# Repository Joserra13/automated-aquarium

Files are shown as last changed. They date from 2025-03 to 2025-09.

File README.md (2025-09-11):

# Automated Aquarium

## Overview

The Automated Aquarium project is designed to transform a traditional aquarium into a smart IoT device. By integrating various sensors and a camera, users can remotely monitor and control multiple aspects of their aquarium environment. Key features include live streaming of the aquarium on Twitch, real-time sensor data visualization, and comprehensive environmental management. The project utilizes a range of technologies, from web development to embedded software.

> **Note:** This is an ongoing project. Features and implementations may evolve over time.

Comprehensive documentation and setup guides are available to assist you in configuring and maintaining your automated aquarium.

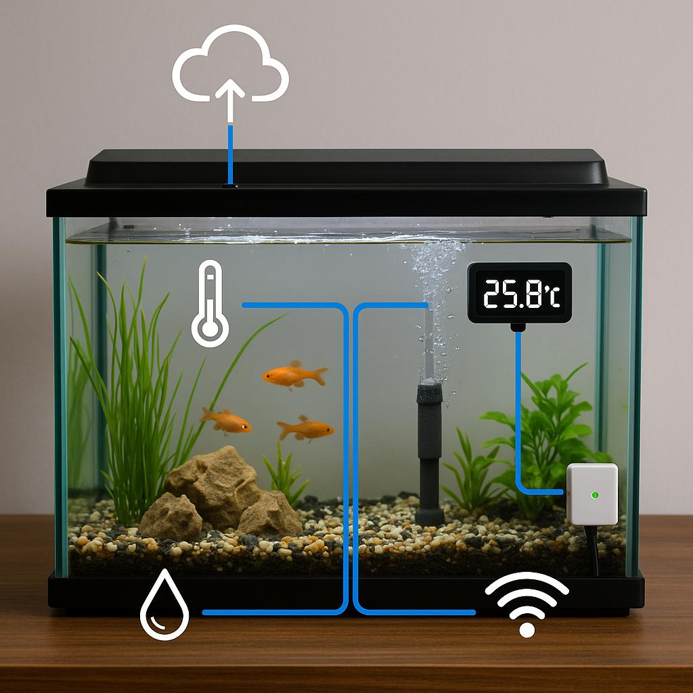
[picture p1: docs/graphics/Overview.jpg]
Architecture


## Automated Aquarium Website

A dedicated website, built with Next.js, serves as the user interface for monitoring and controlling your automated aquarium.

<p align="center">
  <a href="https://automated-aquarium.com">
    
  </a>
</p>

For more information and to get started with the web interface, visit the [automated-aquarium-web](https://github.com/Joserra13/automated-aquarium-web) repository.

<p align="center">
  <a href="https://github.com/Joserra13/automated-aquarium-web">
    
  </a>
</p>

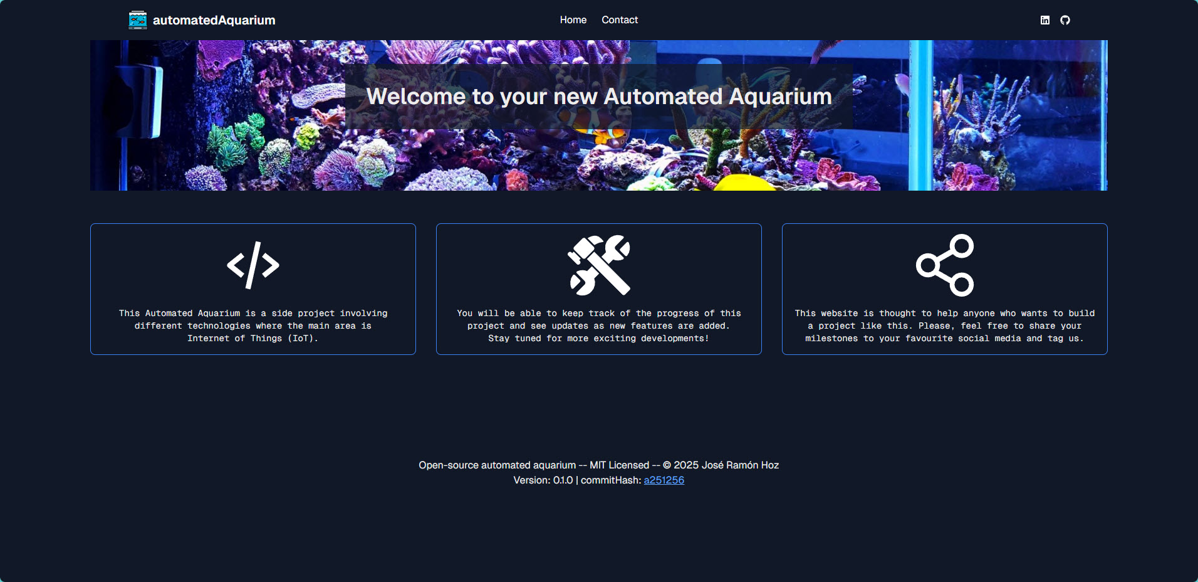
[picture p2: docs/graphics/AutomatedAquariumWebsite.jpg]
AutomatedAquariumWebsite (https://automated-aquarium.com)


## Automated Aquarium Backend

The server, built with node.js, which handles different services where I store data from the aquarium. 

For more information and to get started with the backend of this project, visit the [automated-aquarium-backend](https://github.com/Joserra13/automated-aquarium-backend) repository.

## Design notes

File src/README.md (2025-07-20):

# Components

## Structure

This directory contains detailed information about the components that power the Automated Aquarium system. Additional items will be included as they are developed.

## List of Components

- [Automatic Feeder](./RaspberryPi-Pico-W/Feeder/)
- [Underwater thermistor](./RaspberryPi-Pico-W/Underwater%20Thermistor/)
- [Water Level Sensor](./RaspberryPi-Pico-W/Water%20Level%20Detector/)

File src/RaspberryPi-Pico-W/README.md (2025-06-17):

# Raspberry Pi Pico W

> [!WARNING]  
> To obtain the Firebase keys required for your `credentials.py` file, refer to the [Firebase setup guide](../../../docs/firebase.md). In addition to the Firebase keys, you must also provide your WiFi SSID and password in this file.

## Schematic

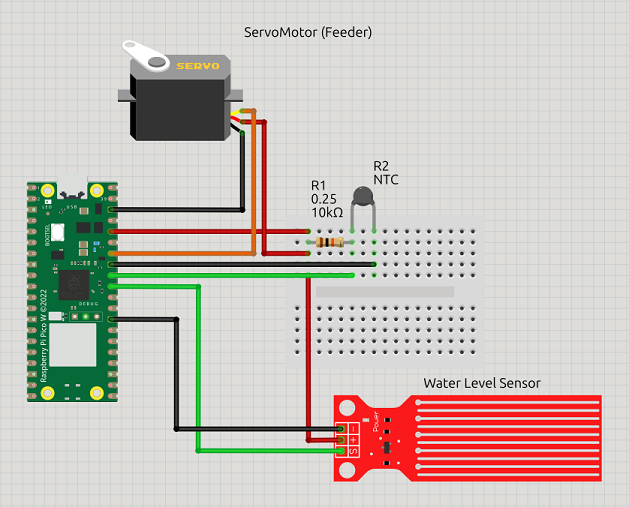
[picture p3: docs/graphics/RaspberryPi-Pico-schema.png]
RaspberryPi-Pico-W-Schematic


## Code

First, connect the Raspberry Pi Pico W to your IDE by following the [official setup guide](https://projects.raspberrypi.org/en/projects/getting-started-with-the-pico/3).

To run the code, you will need the **Servo** object from the **micropython-servo** library:

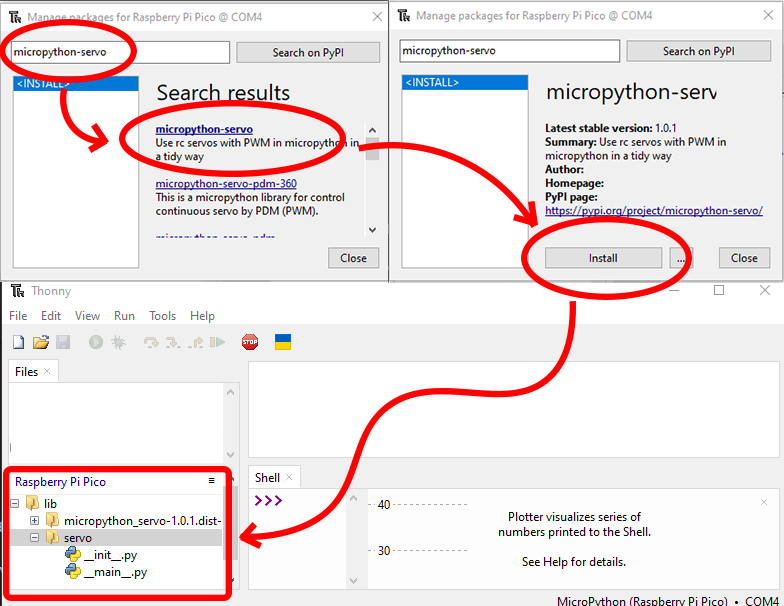
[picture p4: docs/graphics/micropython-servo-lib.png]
Add package


Once the package is installed, copy the [main.py](./main.py), [credentials.py.example](./credentials.py.example) (rename to `credentials.py`), and [utils.py](./utils.py) files to your Raspberry Pi Pico, and run `main.py` in Thonny IDE.

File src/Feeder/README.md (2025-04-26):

# Fish Feeder

## Overview

The automatic fish feeder allows to schedule diferent timeslots to feed your fishes automatically. You only need to worry about placing the food in the storage so, the feeder will provide the food periodically to your fishes.

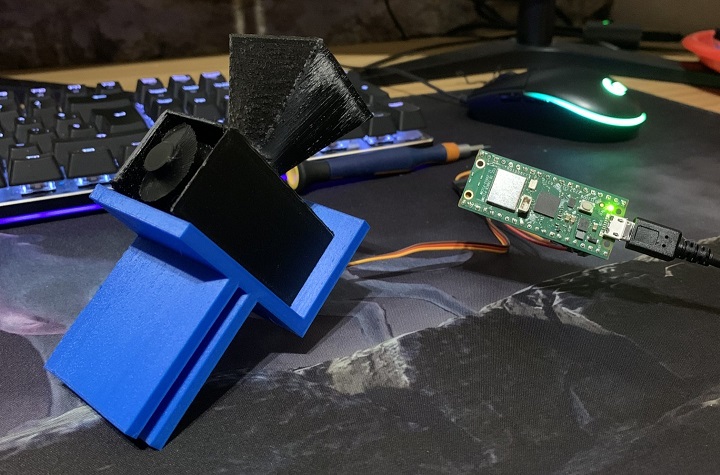
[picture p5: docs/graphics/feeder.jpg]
Feeder


## Materials needed

### Hardware

- Raspberry Pi Pico W (+ charging cable).
- 3d parts printed.
- SG90 Servo (Continuous Rotation).

    >Most of the SG90 servos can only rotate 180 degrees. If this is your case, you can follow the [explained steps](../../docs/hack-servo.md) to hack your servo and convert it into a 360 rotation.

- 3x Male to Female wires.

### Software

- Thonny IDE. See [documentation](https://thonny.org/).

## Circuit

Depending on the device you are using, this schematic might change. In my case, I am using a Raspberry Pi pico W, you can check out the pinout in the following [Raspberry Pi pico documentation](https://www.raspberrypi.com/documentation/microcontrollers/pico-series.html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).

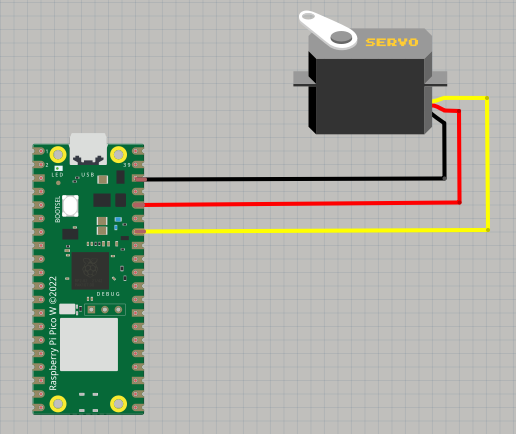
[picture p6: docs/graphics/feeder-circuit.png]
Feeder-circuit


## 3D pieces and assembling

Since some pieces are needed to build the feeder, you can print the different parts from the files under the [3D models](./3D%20models) folder. For the main body, I had to remove the original piece where the Wemos board is stored. In addition, I printed a Raspberry Pi pico W case which I glued to the main body.

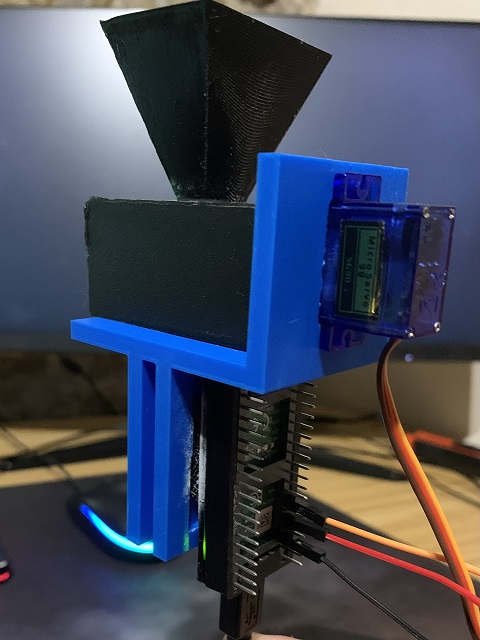
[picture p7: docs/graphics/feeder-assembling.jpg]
Feeder assembling


> [!NOTE]  
> The original 3D files come from the post in [Instructables](https://www.instructables.com/Aquassist-DIY-Automatic-Fish-Feeder-With-Companion/) from [CodersCafeTech](https://www.instructables.com/member/CodersCafeTech/)

## Code

First of all you need to connect the Raspberry Pi pico to your IDE. You can do so by following the original [documentation](https://projects.raspberrypi.org/en/projects/getting-started-with-the-pico/3) from Raspberry Pi.

To run the code, you will need the **Servo** object from the **micropython-servo** library:

Add package

Once, the package is installed, copy the [code](./main.py) and run the script in the Thonny IDE.

## References

- Original idea from CodersCafeTech in [Instructables](https://www.instructables.com/Aquassist-DIY-Automatic-Fish-Feeder-With-Companion/).
- Raspberry Pi pico cover model from [Thingiverse](https://www.thingiverse.com/thing:4793356).

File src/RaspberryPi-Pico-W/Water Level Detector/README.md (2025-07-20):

# Water Level Detector

## Overview

Monitoring water level is essential for maintaining a stable aquatic environment. By adding a water level detector to the project, you can accurately measure and track water levels in real time. This enables automated responses, such as refilling the tank or sending alerts, ensuring optimal conditions for aquatic life and preventing issues caused by low water levels.

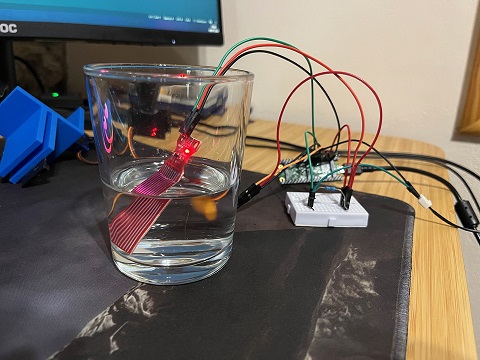
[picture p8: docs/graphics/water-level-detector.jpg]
Water level detector


## Materials Needed

### Hardware

- Raspberry Pi Pico W (with charging cable)
- Water level sensor (analog or digital)
- 3x Female-to-Female jumper wires

### Software

- Thonny IDE. See the [official documentation](https://thonny.org/).

## Circuit

The schematic may vary depending on your device. For the Raspberry Pi Pico W, refer to the [official pinout documentation](https://www.raspberrypi.com/documentation/microcontrollers/pico-series.html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).

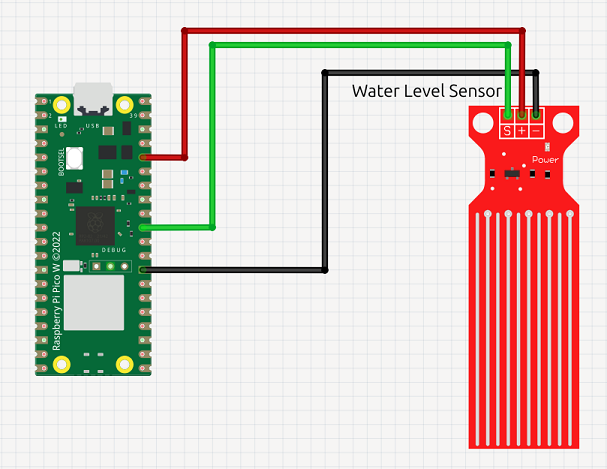
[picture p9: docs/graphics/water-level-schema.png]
Water level circuit


## Code

The code for this project is available under the [RaspberryPi-Pico-W](../) directory.

## References

- [Analog Inputs in Raspberry Pi Pico](https://controlautomaticoeducacion.com/sistemas-embebidos/micropython/adc-pico-esp/)

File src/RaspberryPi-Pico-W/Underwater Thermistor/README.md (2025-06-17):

# Water Thermistor

## Overview

Monitoring water temperature is crucial for maintaining a healthy aquatic environment. By adding a water thermistor to the project, you can accurately measure and track temperature changes in real time. This enables automated responses, such as activating heaters or sending alerts, ensuring optimal conditions for aquatic life and preventing potential issues caused by temperature fluctuations.

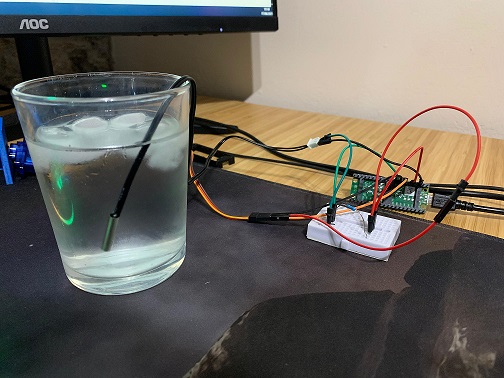
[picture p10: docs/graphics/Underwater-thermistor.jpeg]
Underwater thermistor


## Materials Needed

### Hardware

- Raspberry Pi Pico W (with charging cable)
- NTC thermistor 10K + 0.5%
- 10K Resistor
- Minibreadboard
- 2x Male-to-Male jumper wires
- 3x Male-to-Female jumper wires

### Software

- Thonny IDE. See the [official documentation](https://thonny.org/).

## Circuit

The schematic may vary depending on your device. For the Raspberry Pi Pico W, refer to the [official pinout documentation](https://www.raspberrypi.com/documentation/microcontrollers/pico-series.html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).

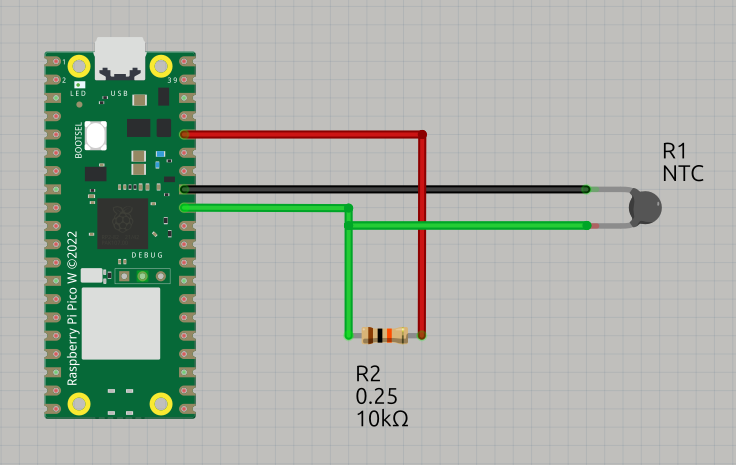
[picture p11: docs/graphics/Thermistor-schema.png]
Thermostat circuit


## Code

The code for this project is available under the [RaspberryPi-Pico-W](../) directory.

## References  

- [Project 29：Temperature Instrument](https://docs.keyestudio.com/projects/KS3025/en/latest/Python_Raspberry-Pi/2.Projects/Project%2029%EF%BC%9ATemperature%20Instrument.html) from Raspberry Pi Pico Learnin Kit.

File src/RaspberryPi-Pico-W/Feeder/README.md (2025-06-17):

# Fish Feeder

## Overview

The automatic fish feeder enables you to schedule multiple feeding times for your fish. Simply ensure that food is placed in the storage compartment—the feeder will automatically dispense food at the designated intervals.

Feeder

## Materials Needed

### Hardware

- Raspberry Pi Pico W (with charging cable)
- 3D-printed parts
- SG90 Servo (Continuous Rotation)

    > **Note:** Most SG90 servos are limited to 180-degree rotation. If this applies to your servo, you can follow the [instructions](../../../docs/hack-servo.md) to modify it for 360-degree rotation.

- 3x Male-to-Female jumper wires

### Software

- Thonny IDE. See the [official documentation](https://thonny.org/).

## Circuit

The schematic may vary depending on your device. For the Raspberry Pi Pico W, refer to the [official pinout documentation](https://www.raspberrypi.com/documentation/microcontrollers/pico-series.html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).

Feeder-circuit

## 3D Parts and Assembly

Several 3D-printed components are required to build the feeder. You can print these parts from the files in the [3D models](./3D%20models) folder. For the main body, the original piece designed for the Wemos board was removed. Additionally, a Raspberry Pi Pico W case was printed and attached to the main body.

Feeder assembling

> [!NOTE]  
> The original 3D files are from [CodersCafeTech](https://www.instructables.com/member/CodersCafeTech/) on [Instructables](https://www.instructables.com/Aquassist-DIY-Automatic-Fish-Feeder-With-Companion/).

## Code

The code for this project is available under the [RaspberryPi-Pico-W](../) directory.

## References

- Original concept by CodersCafeTech on [Instructables](https://www.instructables.com/Aquassist-DIY-Automatic-Fish-Feeder-With-Companion/).
- Raspberry Pi Pico cover model from [Thingiverse](https://www.thingiverse.com/thing:4793356).

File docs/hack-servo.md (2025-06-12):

# Convert SG90 servo into a continuous movement one

## Index

- [Overview](#overview)
- [How can I hack it?](#how-can-i-hack-it)
- [How does it work?](#how-does-it-work)
- [References](#references)

## Overview

Some SG90 servos can only rotate 180 degrees. Since this was the case of the one I own, I needed to perform some modifications into the hardware to convert it into a continuous movement servo.

> [!WARNING]  
> This guide is provided for informational purposes only. Modifying a servo involves risks, including potential damage to your equipment or injury. Proceed at your own risk. I take no responsibility for any harm, damage, or loss resulting from the use or misuse of this information.

## How can I hack it?

1. Disassemble servo.

2. Remove the ending part of the gear shown below:

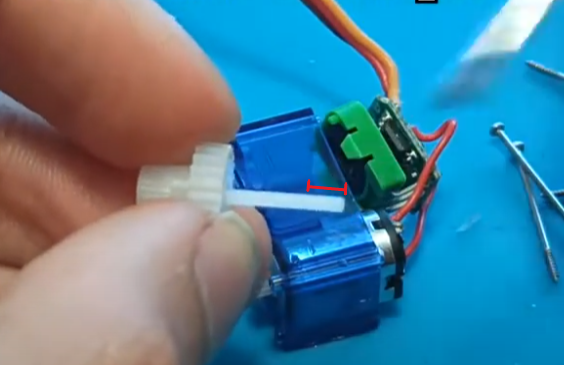
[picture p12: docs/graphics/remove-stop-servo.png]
hack-servo
    

3. Load the following script into your device (e.g. an Raspberry Pi pico) to calibrate the potentiometer.
The potentiometer should me modified so when **my_servo.write(90)** is executed, the servo is fully stopped.

    >**Note**: This script works for python/micropython boards. For Arduinos, you should use another script but following the same commands for the movements.

    ```py
    import time
    from servo import Servo

    # Create our Servo object, assigning the
    # GPIO pin connected the PWM wire of the servo
    my_servo = Servo(pin_id=28)

    while True:
        my_servo.write(90)  # Set the Servo to stop
        time.sleep_ms(1000)  # Wait for 1 second
        
        my_servo.write(0)  # Move the servo clockwise
        time.sleep_ms(1000)  
        
        my_servo.write(180)  # Move the servo counterclockwise
        time.sleep_ms(1000)  
    ```

4. Glue the potentiometer to secure a fixed position and prevent modifications due to vibrations:
    
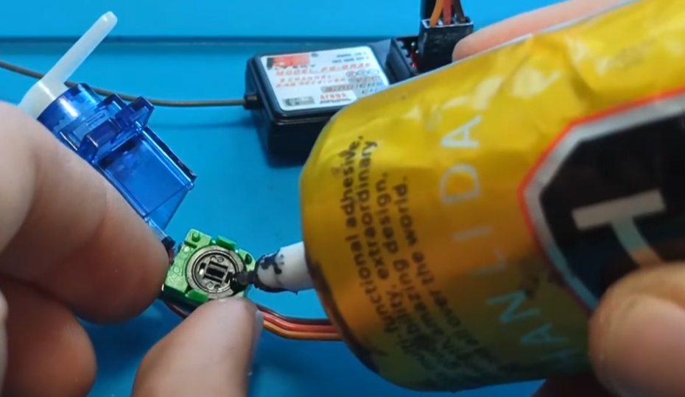
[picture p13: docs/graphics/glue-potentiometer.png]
Glue potentiometer
    

5. Test movement again to check if the servo works as intended.

6. Assemble potentiometer again.

## How does it work?

Continuous rotation servos work similarly to regular angular servos. If your library uses input angles of 0–180°, you can set the speed and direction of a continuous servo like this:
  - 180 - 100% speed counterclockwise
  - 135 - 50% speed counterclockwise
  - 90 - Stopped
  - 45 - 50% speed clockwise
  - 0 - 100% speed clockwise

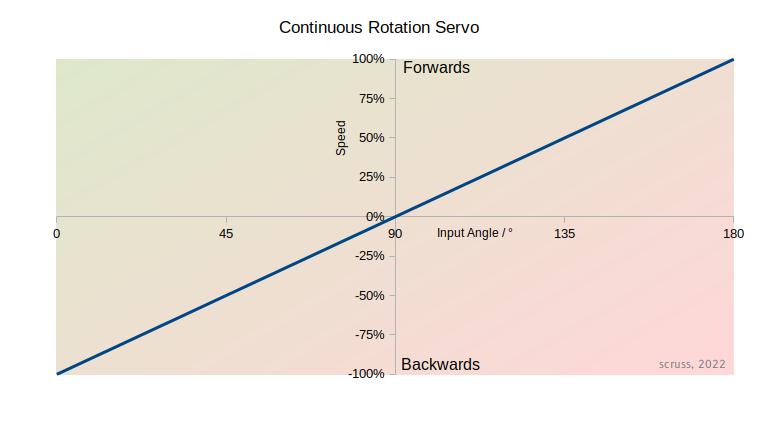
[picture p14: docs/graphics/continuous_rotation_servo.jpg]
Continuous servo graphic


## References:

- [Hack the SG90 servo to make it continuous rotation](https://www.youtube.com/watch?v=4Z-j6bUJTQ8) from H.R.E Systems in Youtube.

- [Calibration script](https://core-electronics.com.au/guides/getting-started-with-servos-examples-with-raspberry-pi-pico/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,Remix%202%20%2D%20Rotational%20Servo%20Control,-Finally%2C%20let%27s%20have) for the potentiometer.

- [Continuous rotation servo graphic](https://forums.raspberrypi.com/viewtopic.php?t=341927) from the Raspberry Pi Forum.

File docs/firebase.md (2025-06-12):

# Setting Up the Firebase Project

## Table of Contents

- [Obtain Credentials](#obtain-credentials)
- [Create the Database](#create-the-database)
- [Accessing the Database](#accessing-the-database)

## Obtain Credentials

1. Navigate to the [Firebase Console](https://console.firebase.google.com/u/3/) and create a new project, following the default configuration steps.

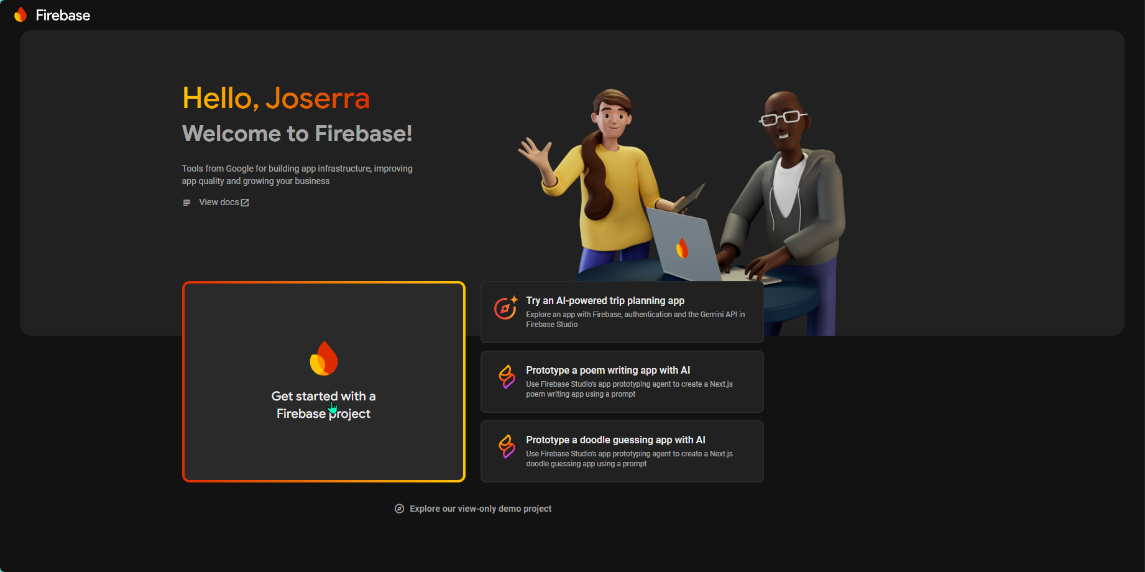
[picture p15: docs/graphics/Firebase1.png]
Get started with Firebase
   

2. Go to the **Authentication** tab and enable both the Email/Password and Google sign-in methods:

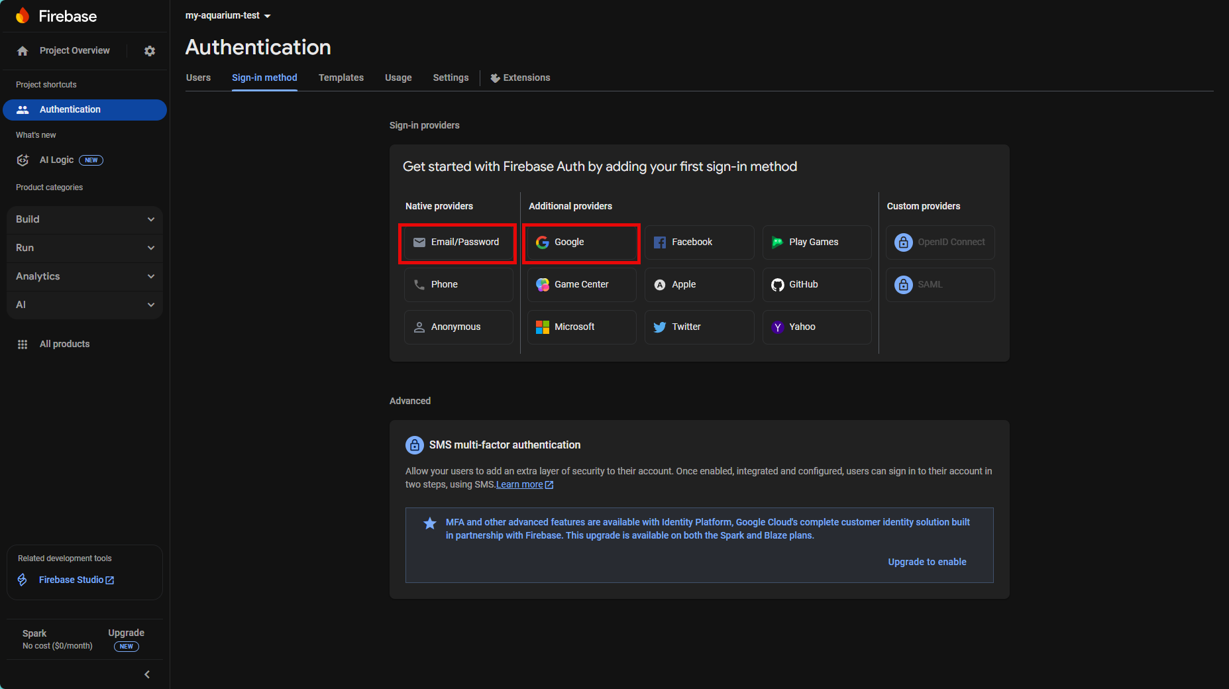
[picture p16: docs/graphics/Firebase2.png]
Authorization
   

3. In **Project Settings**, you will find the information required to populate the variables in the [credentials.py](../src/RaspberryPi-Pico-W/Feeder/credentials.py.example) file:

   ```
   FIREBASE_EMAIL       => The email address used to create the Firebase project.
   FIREBASE_PW          => The password for the email address used.
   FIREBASE_API_KEY     => The Web API key shown in the project settings.
   FIREBASE_PROJECT_ID  => The Project ID shown in the project settings.
   ```

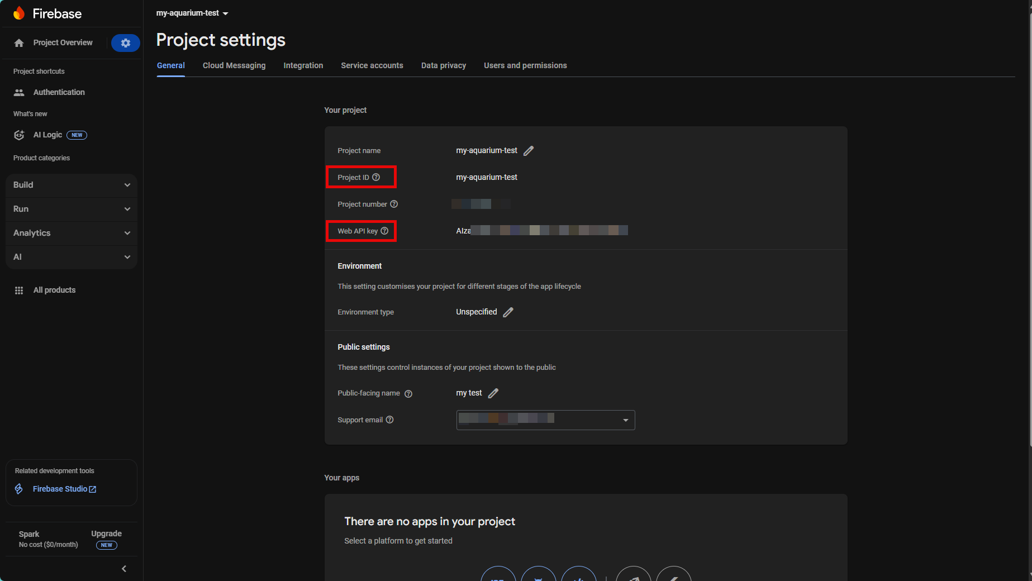
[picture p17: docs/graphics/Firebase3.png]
Project Settings
   

## Create the Database

1. Navigate to **Product categories** → Build → Firestore Database and select **Create database**. The default settings are sufficient.

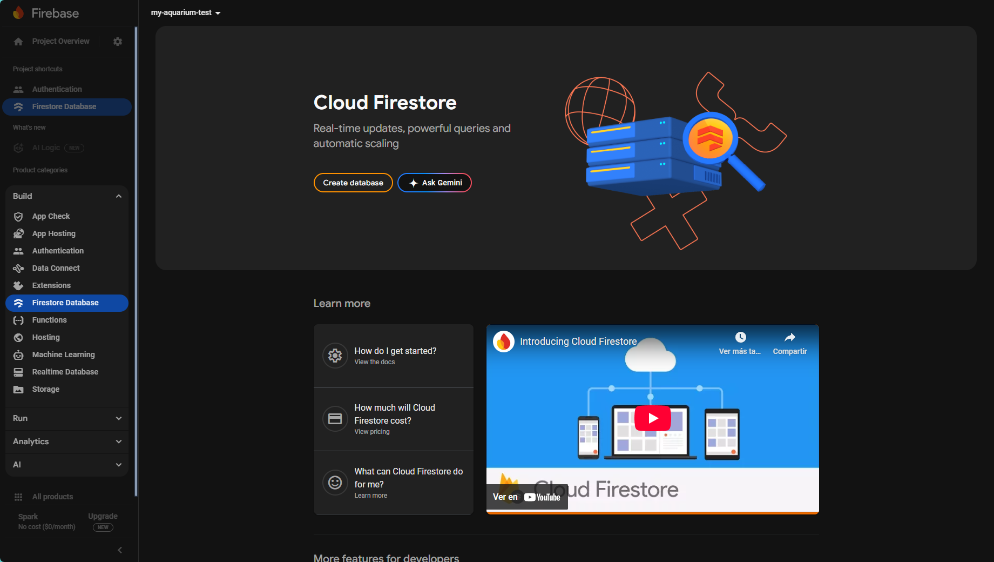
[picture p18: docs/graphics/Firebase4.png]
Create database
   

2. Create a collection to store your data. For example:

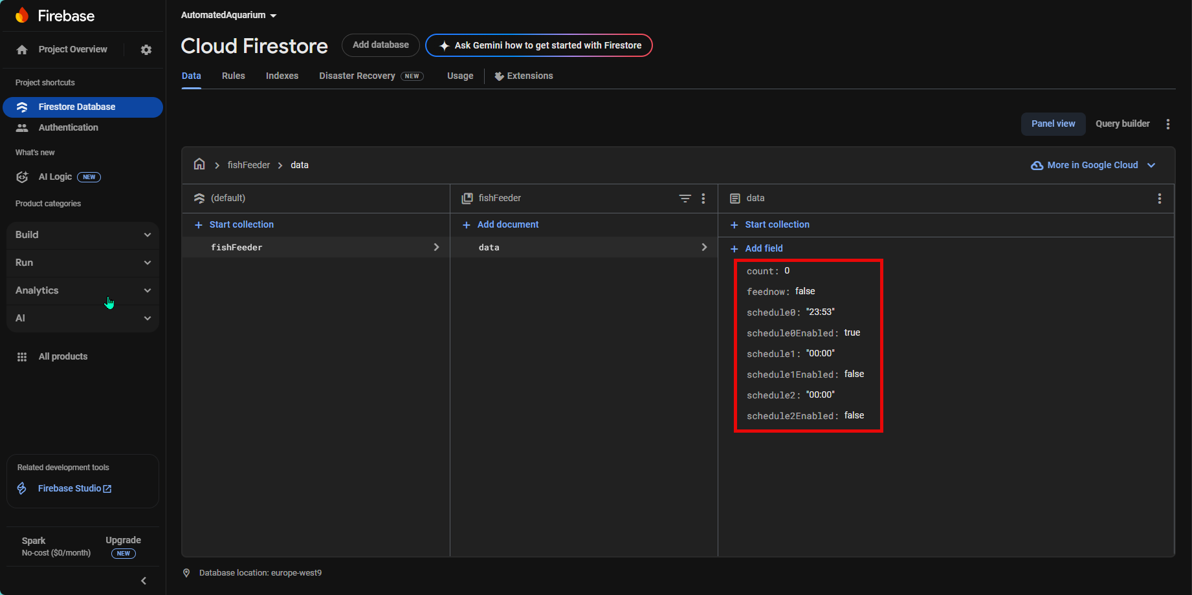
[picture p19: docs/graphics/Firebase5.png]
Create collection
   

3. To allow external queries, update the database rules as shown:

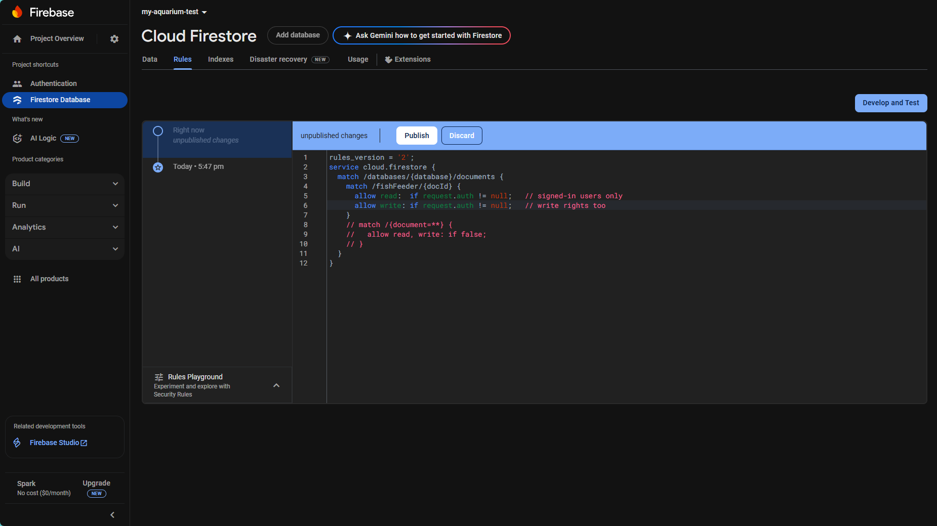
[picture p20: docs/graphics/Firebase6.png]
Set access rules
   

## Accessing the Database

Since the Raspberry Pi Pico will be querying the database, it requires an authentication token. This token is obtained by signing in with your credentials.

### Sign Up with Email/Password

Refer to the [Firebase documentation](https://firebase.google.com/docs/reference/rest/auth?authuser=2#section-create-email-password) for details. This step is only required once.

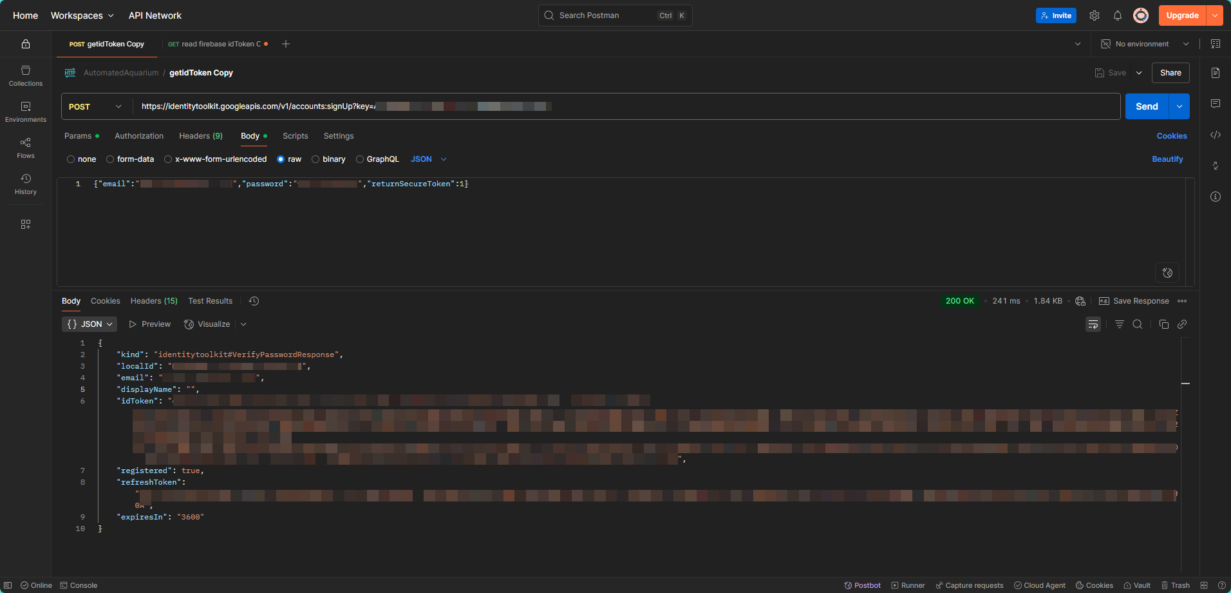
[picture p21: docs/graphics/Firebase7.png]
SignUp


### Sign In with Email/Password

To obtain a token whenever it expires, sign in again as described in the [documentation](https://firebase.google.com/docs/reference/rest/auth?authuser=2#section-sign-in-email-password). The request and response formats are the same as for sign-up.

### Reading Data from the Database

To read data, make a GET request to the Firestore database. Include the **idToken** obtained earlier as a Bearer Token in the Authorization header. See the [official documentation](https://firebase.google.com/docs/firestore/reference/rest/v1/projects.databases.documents/get?authuser=2) for more information.

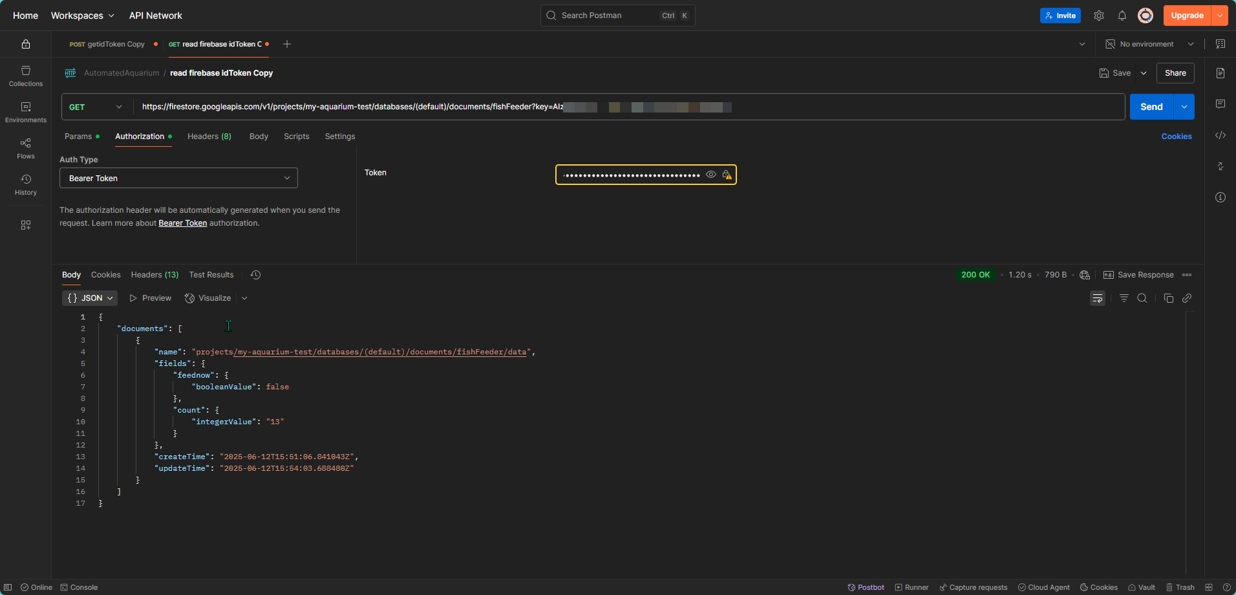
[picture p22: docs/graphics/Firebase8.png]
Read values


Example request body:

```json
{
    "documents": [
        {
            "name": "projects/my-aquarium-test/databases/(default)/documents/fishFeeder/data",
            "fields": {
                "feednow": {
                    "booleanValue": false
                },
                "count": {
                    "integerValue": "13"
                }
            },
            "createTime": "2025-06-12T15:51:06.841043Z",
            "updateTime": "2025-06-12T15:54:03.688480Z"
        }
    ]
}
```

### Writing Data to the Database

To write data, send a POST request to the Firestore endpoint. Ensure the **idToken** is included in the Authorization header as a Bearer Token. Refer to the [official documentation](https://firebase.google.com/docs/firestore/reference/rest/v1/projects.databases.documents/commit?authuser=2) for details on the request format and required fields.

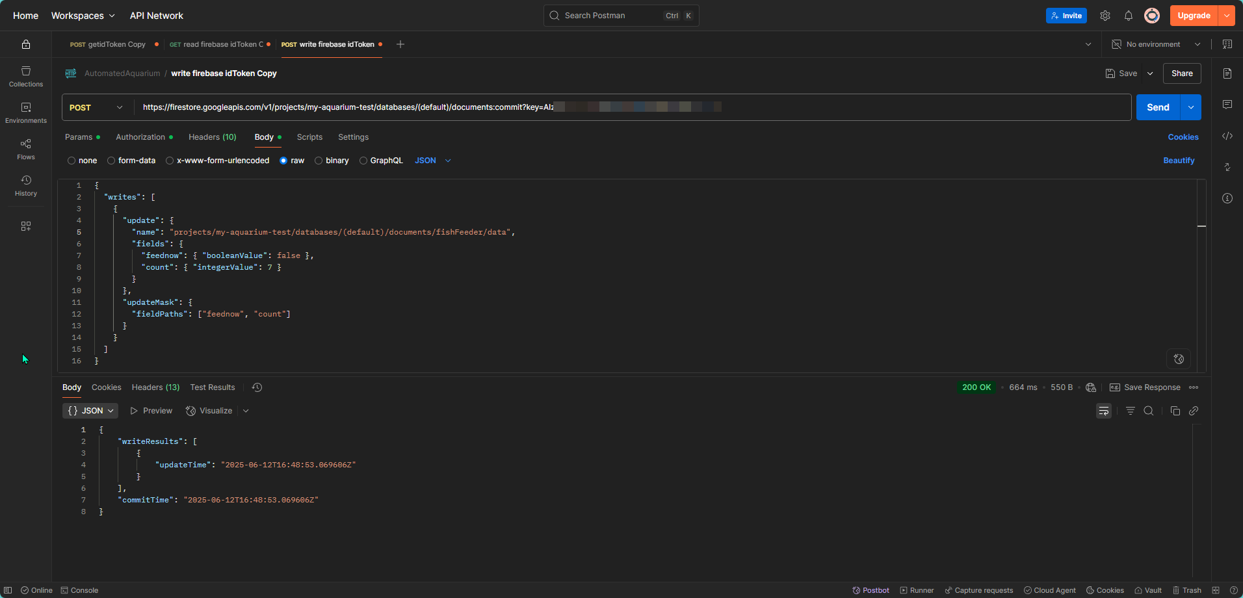
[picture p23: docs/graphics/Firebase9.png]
Write values


Example request body:

```json
{
  "writes": [
    {
      "update": {
        "name": "projects/my-aquarium-test/databases/(default)/documents/fishFeeder/data",
        "fields": {
          "feednow": { "booleanValue": false },
          "count": { "integerValue": 7 }
        }
      },
      "updateMask": {
        "fieldPaths": ["feednow", "count"]
      }
    }
  ]
}
```

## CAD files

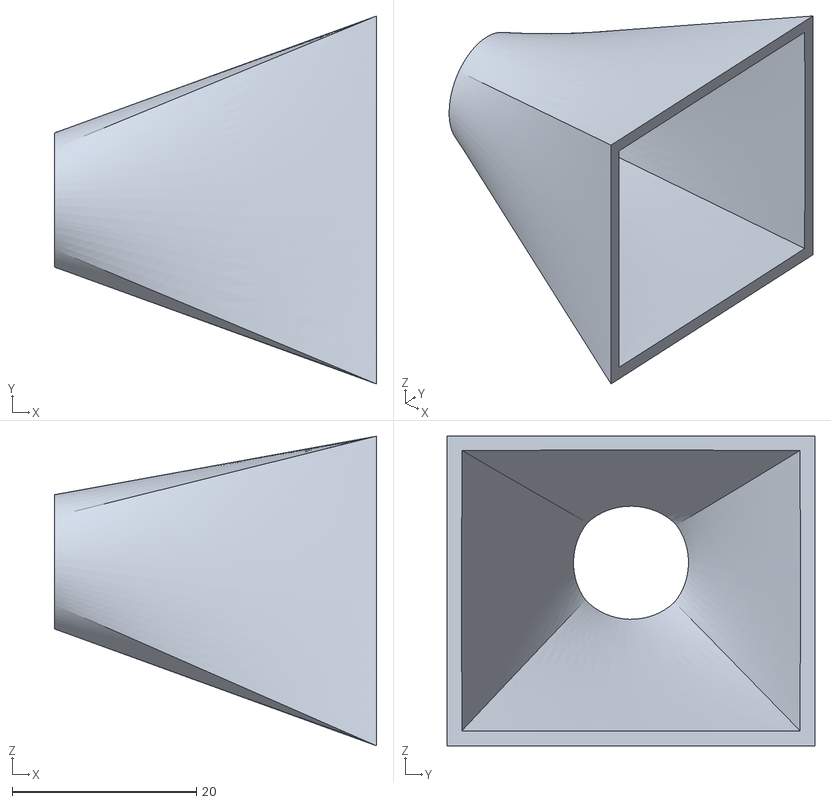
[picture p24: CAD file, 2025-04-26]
src/RaspberryPi-Pico-W/Feeder/3D models/Feeder_storage.stl
35.0 x 40.0 x 33.7

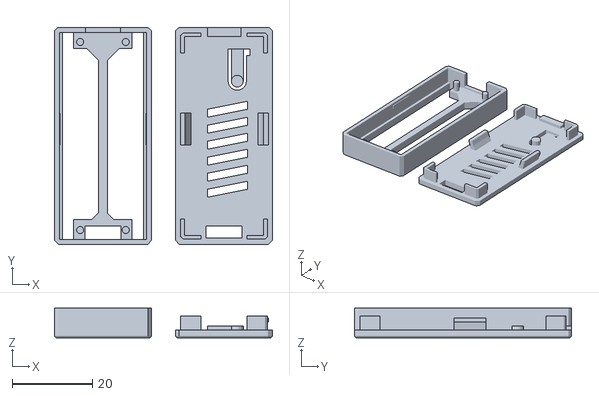
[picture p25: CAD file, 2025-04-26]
src/RaspberryPi-Pico-W/Feeder/3D models/pico2-r.stl
54.5 x 54.2 x 7.40

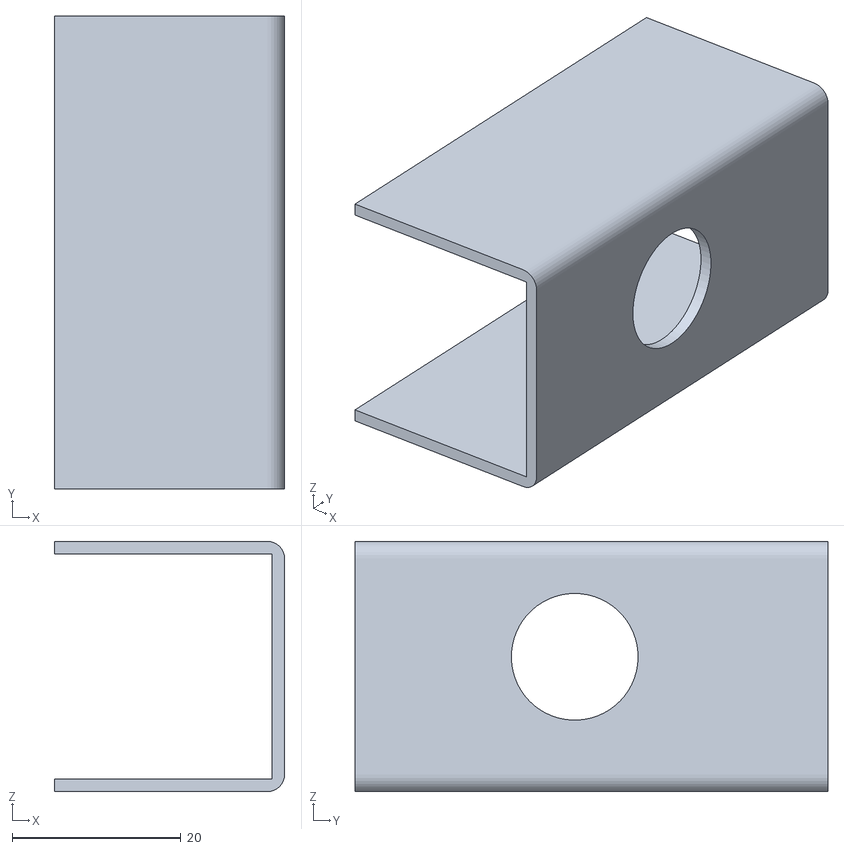
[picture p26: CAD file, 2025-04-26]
src/RaspberryPi-Pico-W/Feeder/3D models/archimedes_screw_cover.stl
27.2 x 56.0 x 29.6

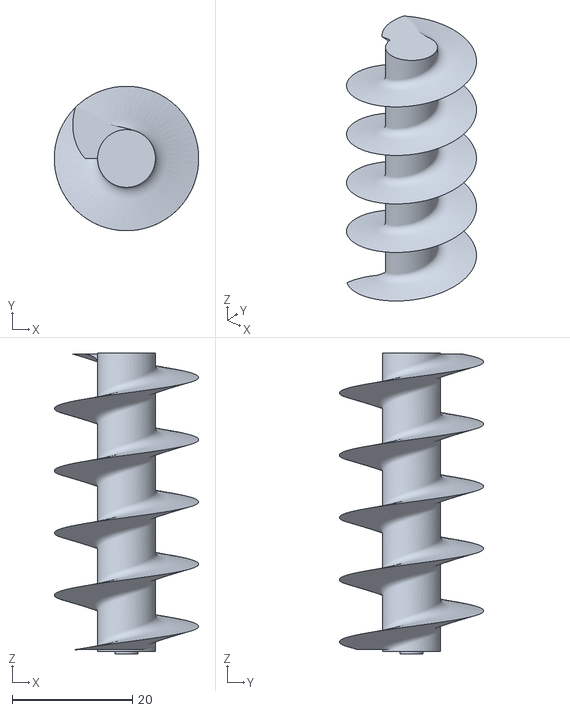
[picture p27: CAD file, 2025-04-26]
src/RaspberryPi-Pico-W/Feeder/3D models/archimedes_screw.stl
24.0 x 24.0 x 50.0

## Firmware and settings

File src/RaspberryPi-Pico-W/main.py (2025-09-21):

# Feeder v3.0
import time
from servo import Servo
import utils
from picozero import pico_led
from machine import ADC

pico_led.on()

# Create our Servo object, assigning the
# GPIO pin connected the PWM wire of the servo
my_servo = Servo(pin_id=28)

# Thermistor constants
Thermistor_PIN = 27           # GP27 = ADC1
thermistor = ADC(Thermistor_PIN)

# WaterLevel constants
WaterLevel_PIN = 26           # GP26 = ADC0
water_level = ADC(WaterLevel_PIN)

TIMEOUTS = {
    "token": 3540,
    "values": 5,
    "schedule": 600
}

last_actions = {
    "token": time.time() - 3600,
    "values": time.time() - 2,
    "schedule": time.time() - 600
}

#Variable to store the scheduledates
schedules = [
    {"time": 0, "enabled": False},
    {"time": 0, "enabled": False},
    {"time": 0, "enabled": False}
]

utils.connect()

def time_string_to_seconds(time_str):
    # Split the string by colon
    hours, minutes = time_str.split(":")
    
    # Convert to integers
    hours = int(hours)
    minutes = int(minutes)
    
    # Calculate seconds since midnight
    seconds_since_midnight = hours * 3600 + minutes * 60
    
    return seconds_since_midnight

def feedTheFish():
    print("\nFeeding time!")
    ## TODO: Set the correct movement and timing for the food ##
    my_servo.write(0)    # Move the servo clockwise
    time.sleep_ms(750)  # Wait for 1 second
    
    my_servo.write(90)    # Stop the servo
    time.sleep_ms(1000)  # Wait for 1 second

while True:

    current_time = time.localtime()
    current_seconds = current_time[3] * 3600 + current_time[4] * 60 + current_time[5]

    if any(s["enabled"] and current_seconds == s["time"] for s in schedules):
        #Move the servo to feed
        feedTheFish()
        data = utils.readFirebase(idToken)
        utils.writeFirebase(idToken, valueFeed=False, valueCount=int(data["count"].get("integerValue"))+1)
    
    if (time.time() - last_actions["token"]) > TIMEOUTS["token"]:    
        #Need to ask for a token
        #print("Ask for token")
        try:
            idToken = utils.getToken()
            print(idToken)
            last_actions["token"] = time.time()
        except Exception as e:
            print(f"Error getting the token: {e}")
        
    if(time.time() - last_actions["values"]) > TIMEOUTS["values"]:
        
        rawTemp = thermistor.read_u16()  # 16-bit ADC (0-65535)
        rawWaterLevel = water_level.read_u16()
        
        temp_c = utils.read_temperature(rawTemp)
        waterLevel = utils.read_waterLevel(rawWaterLevel)
        #print(f"waterLevel {waterLevel}")
        
        #Query the value
        try:
            print(f"\nRead values")
            data = utils.readFirebase(idToken)
            #print(f"feednow: {data["feednow"].get("booleanValue")}")
            last_actions["values"] = time.time()
            
            if data["feednow"].get("booleanValue"):
                
                feedTheFish()
                
                #print("Update values in Firebase")
                utils.writeFirebase(idToken, valueFeed=False, valueCount=int(data["count"].get("integerValue"))+1)
            
            utils.writeFirebase(idToken, valueTemp=temp_c, valueWaterLevel=waterLevel)                
                
        except ValueError:
            print("Syntax error in JSON")
        except Exception as e:
            print(f"Error updating values: {e}")
        except:
            print("Unknown error")
            
    if (time.time() - last_actions["schedule"]) > TIMEOUTS["schedule"]:
        #Read if schedules are enabled
        try:
            print(f"\nRead Schedule values")
            data = utils.readFirebase(idToken)
            
            for x in range(3):
                varName = f"schedule{x}"
                schedule_enabled = data[f"{varName}Enabled"].get("booleanValue")
                schedules[x]["enabled"] = schedule_enabled
                
                if schedule_enabled:
                    schedules[x]["time"] = time_string_to_seconds(data[varName].get("stringValue"))
                
                print(f"Schedule {x}: {schedules[x]}")
            
            last_actions["schedule"] = time.time()
        except Exception as e:
            print(f"Error reading schedule: {e}")

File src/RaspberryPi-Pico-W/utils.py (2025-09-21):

import credentials
import network
import urequests
import ujson
import time
from math import log
import gc

def connect():
    #Connect to WLAN
    wlan = network.WLAN(network.STA_IF)
    wlan.active(True)
    wlan.connect(credentials.WIFI_SSID, credentials.WIFI_PW)
    # Wait for connect or fail
    max_wait = 10
    while max_wait > 0:
        if wlan.status() < 0 or wlan.status() >= 3:
            break
        max_wait -= 1
        print('Waiting for connection...')
        time.sleep(1)

    # Handle connection error
    if wlan.status() != 3:
        raise RuntimeError('Network connection failed')
    else:
        print('Connected')
        status = wlan.ifconfig()
        print('IP = ' + status[0])
        
def getToken():
    post_data = ujson.dumps({"email":credentials.FIREBASE_EMAIL,"password":credentials.FIREBASE_PW,"returnSecureToken": 1 })
    r = urequests.post("https://identitytoolkit.googleapis.com/v1/accounts:signInWithPassword?key="+credentials.FIREBASE_API_KEY,headers={'content-type': 'application/json'}, data = post_data)
    idToken = ujson.loads(r.content)["idToken"]
    r.close()
    
    return idToken

def readFirebase(idToken):
    try:
      r = urequests.get(f"https://firestore.googleapis.com/v1/projects/{credentials.FIREBASE_PROJECT_ID}/databases/(default)/documents/fishFeeder?key="+credentials.FIREBASE_API_KEY,headers={'Authorization': 'Bearer ' + idToken, })
      data = ujson.loads(r.content)["documents"][0]["fields"]
    except Exception as e:
      print("Error reading Firebase:", e)
    finally:
      r.close()
      gc.collect();
    return data

def writeFirebase(idToken, valueFeed=None, valueCount=None, valueTemp=None, valueWaterLevel=None):
    
    try:
      body=ujson.dumps({})
      
      if valueFeed is not None and valueCount is not None:
          body = ujson.dumps({
              "writes": [
              {
                "update": {
                  "name": "projects/"+ credentials.FIREBASE_PROJECT_ID +"/databases/(default)/documents/fishFeeder/data",
                  "fields": {
                    "feednow": { "booleanValue": valueFeed },
                    "count": { "integerValue": valueCount}
                  }
                },
                "updateMask": {
                  "fieldPaths": ["feednow", "count"]
                }
              }]
          })
      elif valueTemp is not None and valueWaterLevel is not None:
          body = ujson.dumps({
              "writes": [
              {
                "update": {
                  "name": "projects/"+ credentials.FIREBASE_PROJECT_ID +"/databases/(default)/documents/fishFeeder/data",
                  "fields": {
                    "waterTemperature": { "doubleValue": valueTemp },
                    "waterLevel": { "doubleValue": valueWaterLevel }
                  }
                },
                "updateMask": {
                  "fieldPaths": ["waterTemperature", "waterLevel"]
                }
              }]
          })
      
      post_data = body
      r = urequests.post(f"https://firestore.googleapis.com/v1/projects/{credentials.FIREBASE_PROJECT_ID}/databases/(default)/documents:commit?key="+credentials.FIREBASE_API_KEY,headers={'Authorization': 'Bearer ' + idToken, }, data = post_data)
    except Exception as e:
      print("Error writing Firebase:", e)
    finally:
      r.close()
      gc.collect();

def read_temperature(raw):
  voltage = raw / 65535.0 * 3.3
  Rt = 10 * voltage / (3.3-voltage)
  tempK = (1 / (1 / (273.15+25) + (log(Rt/10)) / 3950))
  temp_c = float(tempK - 273.15)

  return temp_c

def read_waterLevel(raw):
    factor_16 = 22.5 / (65535) #Liters = Max Analog value
    voltage = raw * factor_16
    
    return voltage

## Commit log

2025-04-25 Docs(Servo): How to hack servo into continuous movement
2025-04-25 Docs(Servo): Add missing steps
2025-04-25 Feat(Servo): Add warning
2025-04-26 Feat(Feeder): Add files
    [Feeder_storage.stl, archimedes_screw.stl, archimedes_screw_cover.stl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]
2025-05-12 Fix: Refactor filee paths
    [Feeder_storage.stl, archimedes_screw.stl, archimedes_screw_cover.stl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]
2025-06-12 feat: add timing to read an error handling
    [main.py]
2025-06-12 fix: set project id dynamic
    [utils.py]
2025-06-12 fix: add idToken for write req
    [main.py]
2025-06-13 docs(feeder): clarify device
2025-06-16 feat(rasp-pico): add water temperature sensor
2025-06-16 fix(rasp-pico): temperature formula
2025-06-16 fix(rasp-pico): temperature formula - remove math.log
    [utils.py]
2025-06-17 feat(thermistor): add readme
2025-06-17 feat(rapbpi): Add entry of thermistor
2025-06-17 fix(): move raspbpi schematic to the correct folder
2025-07-19 feat(rasp-pi-pico): Add a water level detector
2025-07-20 feat(rasp-pi-pico): Add WaterLevel docu
2025-07-20 feat(rasp-pico): add water level to schematic
2025-07-20 fix(rasp-pico): Update pinout for thermistor schematic
2025-07-28 feat(): turn on led when working
2025-09-16 fix(feeder): Reduce time of rotating the servo
    [main.py]
2025-09-16 fix(feeder): make the liters count with a reference
    [utils.py]
2025-09-19 feat(): Add exceptions to errors and comment prints
    [main.py]
2025-09-21 fix(): Add garbage collector for preventing mem leaks
    [utils.py]
